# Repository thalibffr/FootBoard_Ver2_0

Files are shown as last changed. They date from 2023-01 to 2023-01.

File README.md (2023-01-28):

# Footboard ICHIRO Ver2.0

New Board Design for Foot Pressure of humanoid robot ICHIRO ITS

In this new design analog sensor data readings use ads1262

[Top view]
loadcell_v2 top

[Bottom view]
loadcell_v2 bottom

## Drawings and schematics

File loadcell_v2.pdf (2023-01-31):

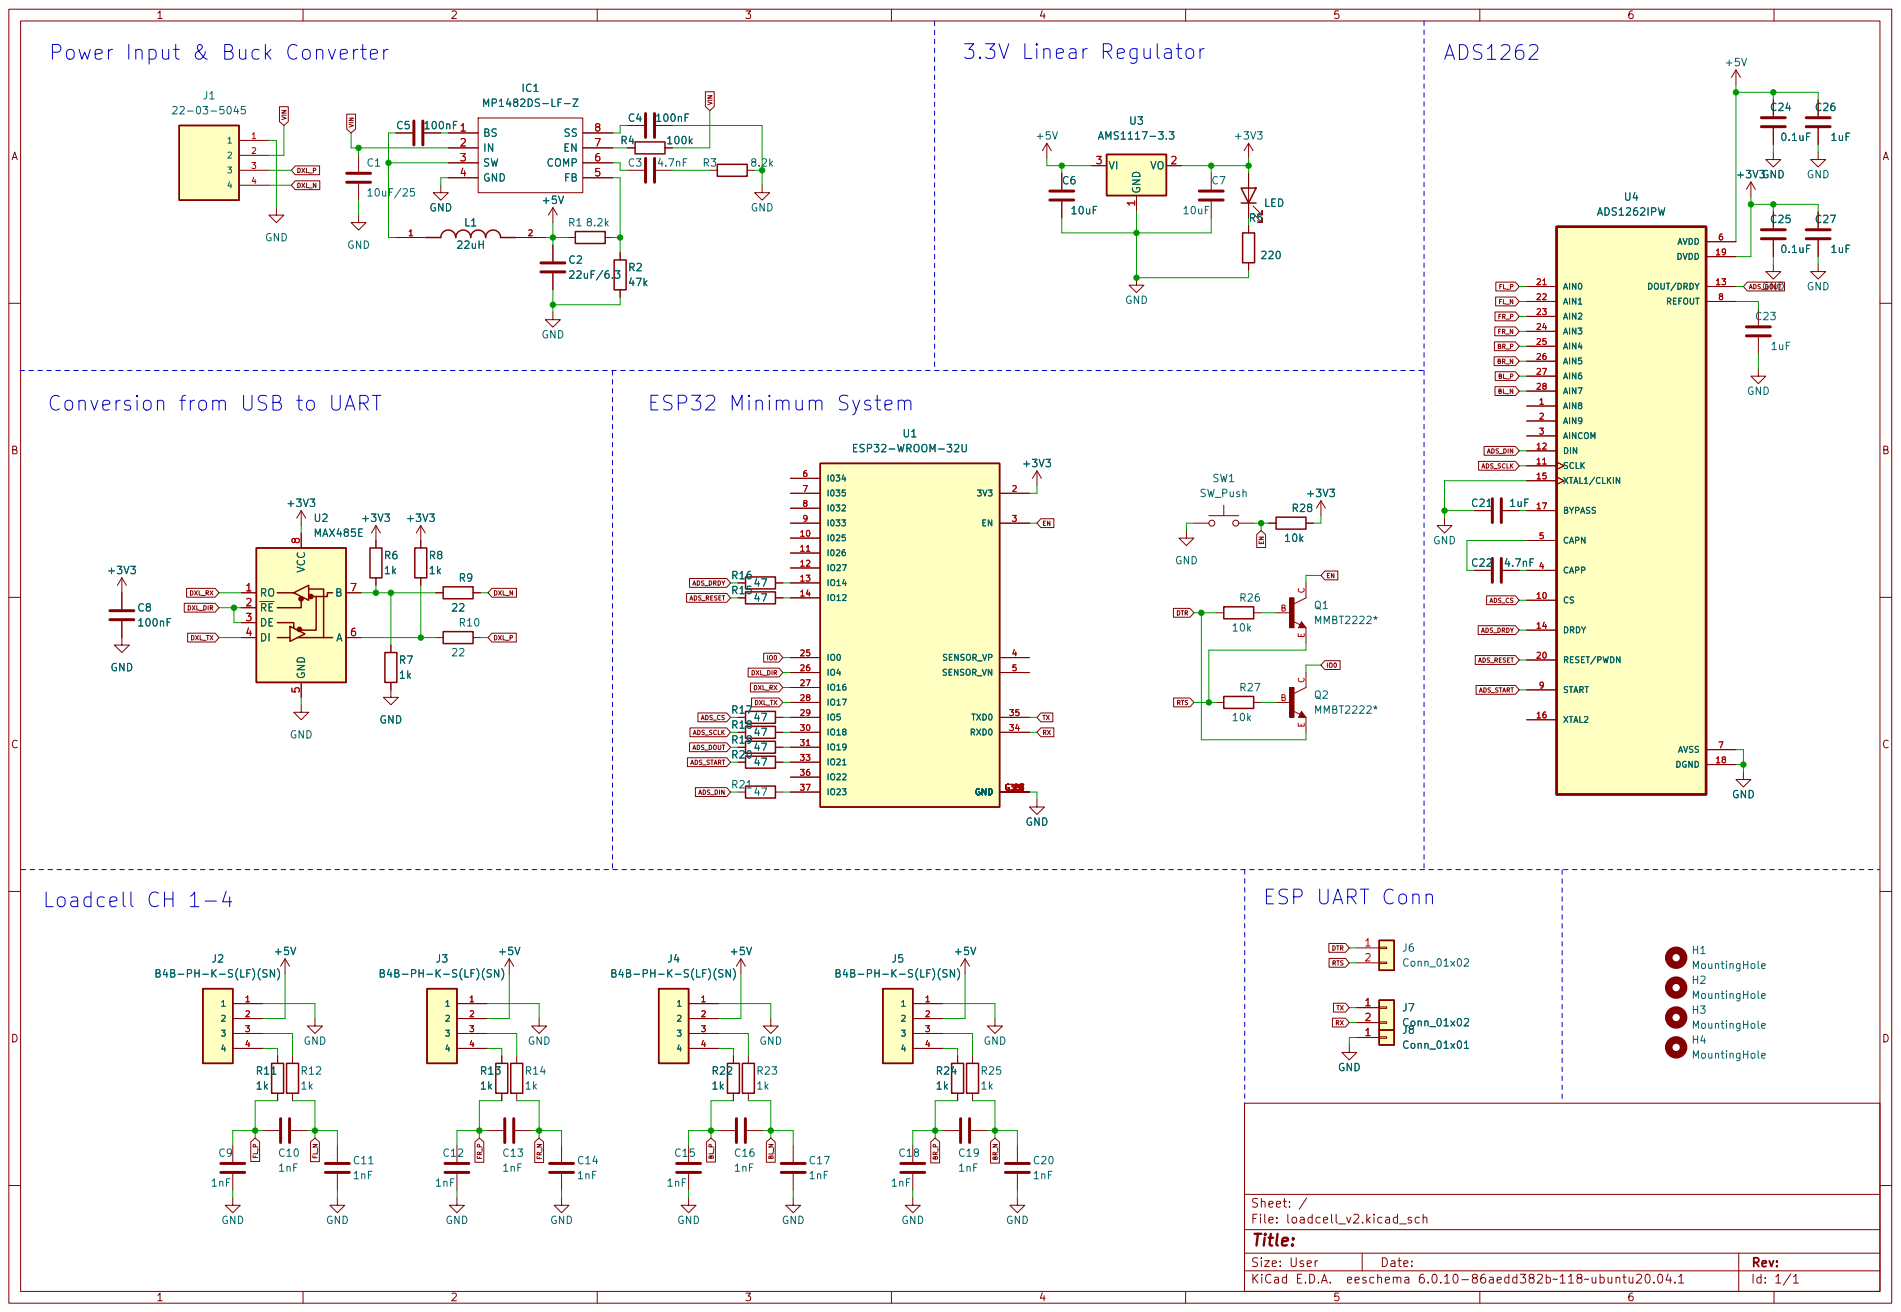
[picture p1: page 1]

Power Input & Buck Converter

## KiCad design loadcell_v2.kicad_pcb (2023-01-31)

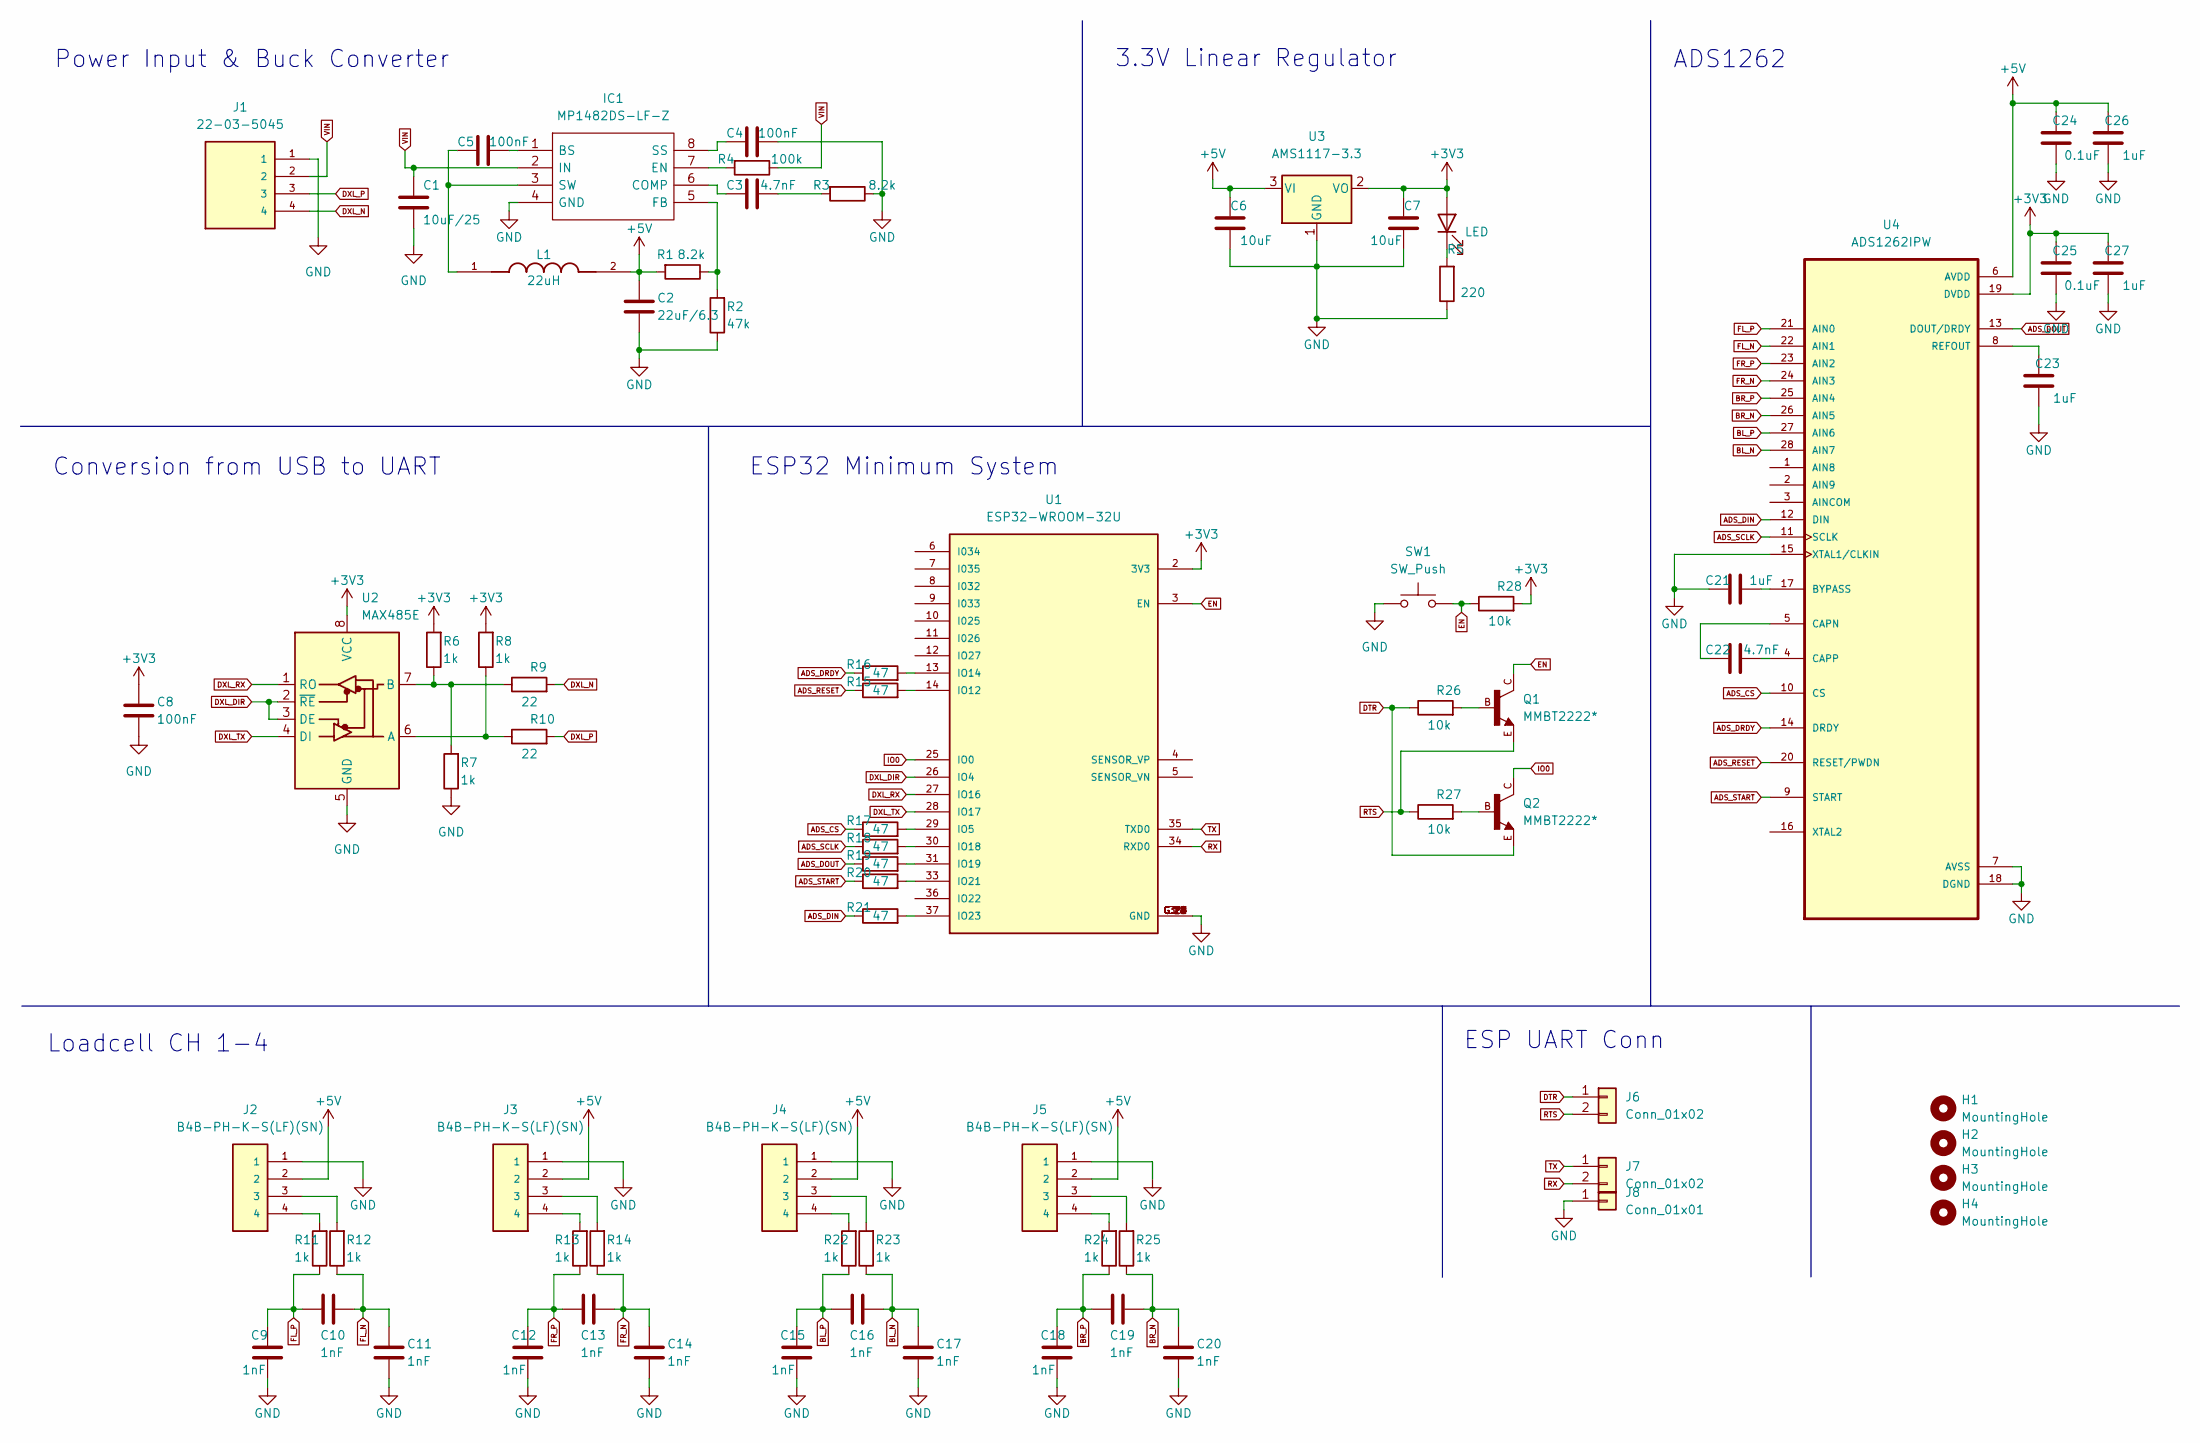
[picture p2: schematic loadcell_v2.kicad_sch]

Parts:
C1: 10uF/25; C_0805_2012Metric
C2: 22uF/6.3; C_0805_2012Metric
C3, C22: 4.7nF; C_0805_2012Metric
C4, C5, C8: 100nF; C_0805_2012Metric
C6, C7: 10uF; C_0805_2012Metric
C9, C10, C11, C12, C13, C14, C15, C16, C17, C18, C19, C20: 1nF; C_0805_2012Metric
C21, C23, C26, C27: 1uF; C_0805_2012Metric
C24, C25: 0.1uF; C_0805_2012Metric
D1: LED; LED_0805_2012Metric
H1, H2, H3, H4: MountingHole; MountingHole_3mm
IC1: MP1482DS-LF-Z; SOIC127P600X175-8N; Manufacturer_Part_Number MP1482DS-LF-Z; Mouser Part Number 946-MP1482DSLFZ
J1: 22-03-5045; MOLEX_22-03-5045; PARTREV B
J2, J3, J4, J5: B4B-PH-K-S(LF)(SN); JST_B4B-PH-K-S(LF)(SN)
J6, J7: Conn_01x02; PinHeader_1x02_P2.54mm_Vertical
J8: Conn_01x01; PinHeader_1x01_P2.54mm_Vertical
L1: 22uH; IND_VLS6045EX-3R3N; PARTREV N/A
Q1, Q2: MMBT2222*; SOT23-BEC
R1, R3: 8.2k; R_0805_2012Metric
R2: 47k; R_0805_2012Metric
R4: 100k; R_0805_2012Metric
R5: 220; R_0805_2012Metric
R6, R7, R8, R11, R12, R13, R14, R22, R23, R24, R25: 1k; R_0805_2012Metric
R9, R10: 22; R_0805_2012Metric
R15, R16, R17, R18, R19, R20, R21: 47; R_0805_2012Metric
R26, R27, R28: 10k; R_0805_2012Metric
SW1: SW_Push; SW_SPST_CK_RS282G05A3
U1: ESP32-WROOM-32U; XCVR_ESP32-WROOM-32U; PARTREV V1.9
U2: MAX485E; SOIC127P600X175-8N
U3: AMS1117-3.3; SOT229P700X180-4N
U4: ADS1262IPW; SOP65P640X120-28N

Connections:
+3V3: C7.2, C8.2, C25.2, C27.2, D1.2 (A), R6.2, R8.2, R28.2, U1.2 (3V3), U2.8 (VCC), U3.2 (VO), U4.19 (DVDD)
+5V: C2.2, C6.2, C24.2, C26.2, J2.2, J3.2, J4.2, J5.2, L1.2, R1.2, U3.3 (VI), U4.6 (AVDD)
ADS_CS: R17.1, U4.10 (CS)
ADS_DIN: R21.1, U4.12 (DIN)
ADS_DOUT: R19.1, U4.13 (DOUT/DRDY)
ADS_DRDY: R16.1, U4.14 (DRDY)
ADS_RESET: R15.1, U4.20 (RESET/PWDN)
ADS_SCLK: R18.1, U4.11 (SCLK)
ADS_START: R20.1, U4.9 (START)
BL_N: C16.2, C17.2, R23.1, U4.28 (AIN7)
BL_P: C15.2, C16.1, R22.1, U4.27 (AIN6)
BR_N: C19.2, C20.2, R25.1, U4.26 (AIN5)
BR_P: C18.2, C19.1, R24.1, U4.25 (AIN4)
DTR: J6.1, Q2.E, R26.1; also elsewhere on the board
DXL_DIR: U1.26 (IO4), U2.2 (~RE), U2.3 (DE)
DXL_N: J1.4, R9.2
DXL_P: J1.3, R10.2
DXL_RX: U1.27 (IO16), U2.1 (RO)
DXL_TX: U1.28 (IO17), U2.4 (DI)
EN: Q1.C, R28.1, SW1.2, U1.3 (EN)
FL_N: C10.2, C11.2, R12.1, U4.22 (AIN1)
FL_P: C9.2, C10.1, R11.1, U4.21 (AIN0)
FR_N: C13.2, C14.2, R14.1, U4.24 (AIN3)
FR_P: C12.2, C13.1, R13.1, U4.23 (AIN2)
GND: C1.2, C2.1, C4.1, C6.1, C7.1, C8.1, C9.1, C11.1, C12.1, C14.1, C15.1, C17.1, C18.1, C20.1, C21.1, C23.1, C24.1, C25.1, C26.1, C27.1, IC1.4 (GND), J1.1, J2.1, J3.1, J4.1, J5.1, J8.1, R2.1, R3.1, R5.1, R7.1, SW1.1, U1.1 (GND), U1.38 (GND), U1.G.11 (GND), U1.G.12 (GND), U1.G.13 (GND), U1.G.14 (GND), U1.G.15 (GND), U1.G.16 (GND), U1.G.17 (GND), U1.G.18 (GND), U1.G.19 (GND), U1.G.20 (GND), U1.G.21 (GND), U1.G.22 (GND), U2.5 (GND), U3.1 (GND), U4.7 (AVSS), U4.15 (XTAL1/CLKIN), U4.18 (DGND)
IO0: Q2.C, U1.25 (IO0)
unnamed: C3.1, R3.2
unnamed: C3.2, IC1.6 (COMP)
unnamed: C4.2, IC1.8 (SS)
unnamed: C5.1, IC1.1 (BS)
unnamed: C5.2, IC1.3 (SW), L1.1
unnamed: C21.2, U4.17 (BYPASS)
unnamed: C22.1, U4.4 (CAPP)
unnamed: C22.2, U4.5 (CAPN)
unnamed: C23.2, U4.8 (REFOUT)
unnamed: D1.1 (K), R5.2
unnamed: IC1.5 (FB), R1.1, R2.2
unnamed: IC1.7 (EN), R4.2
unnamed: J2.3, R12.2
unnamed: J2.4, R11.2
unnamed: J3.3, R14.2
unnamed: J3.4, R13.2
unnamed: J4.3, R23.2
unnamed: J4.4, R22.2
unnamed: J5.3, R25.2
unnamed: J5.4, R24.2
unnamed: Q1.B, R26.2
unnamed: Q2.B, R27.2
unnamed: R6.1, R7.2, R9.1, U2.7 (B)
unnamed: R8.1, R10.1, U2.6 (A)
unnamed: R15.2, U1.14 (IO12)
unnamed: R16.2, U1.13 (IO14)
unnamed: R17.2, U1.29 (IO5)
unnamed: R18.2, U1.30 (IO18)
unnamed: R19.2, U1.31 (IO19)
unnamed: R20.2, U1.33 (IO21)
unnamed: R21.2, U1.37 (IO23)
RTS: J6.2, Q1.E, R27.1; also elsewhere on the board
RX: J7.2, U1.34 (RXD0); also elsewhere on the board
TX: J7.1, U1.35 (TXD0); also elsewhere on the board
VIN: C1.1, IC1.2 (IN), J1.2, R4.1

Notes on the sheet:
3.3V Linear Regulator
Loadcell CH 1-4
Power Input & Buck Converter
ESP32 Minimum System
Conversion from USB to UART
ADS1262
ESP UART Conn

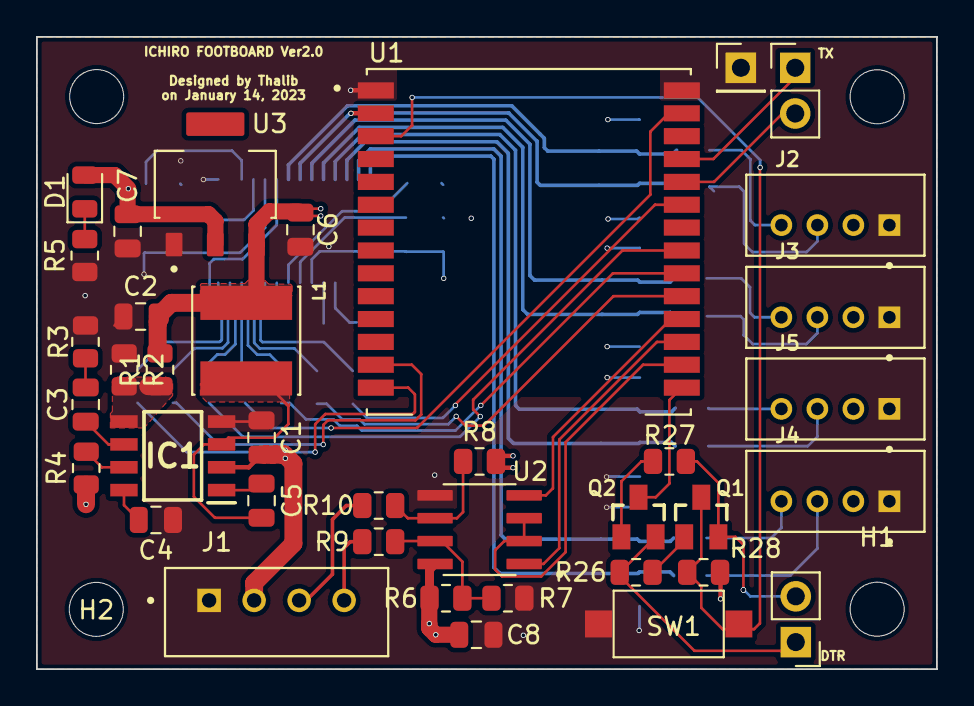
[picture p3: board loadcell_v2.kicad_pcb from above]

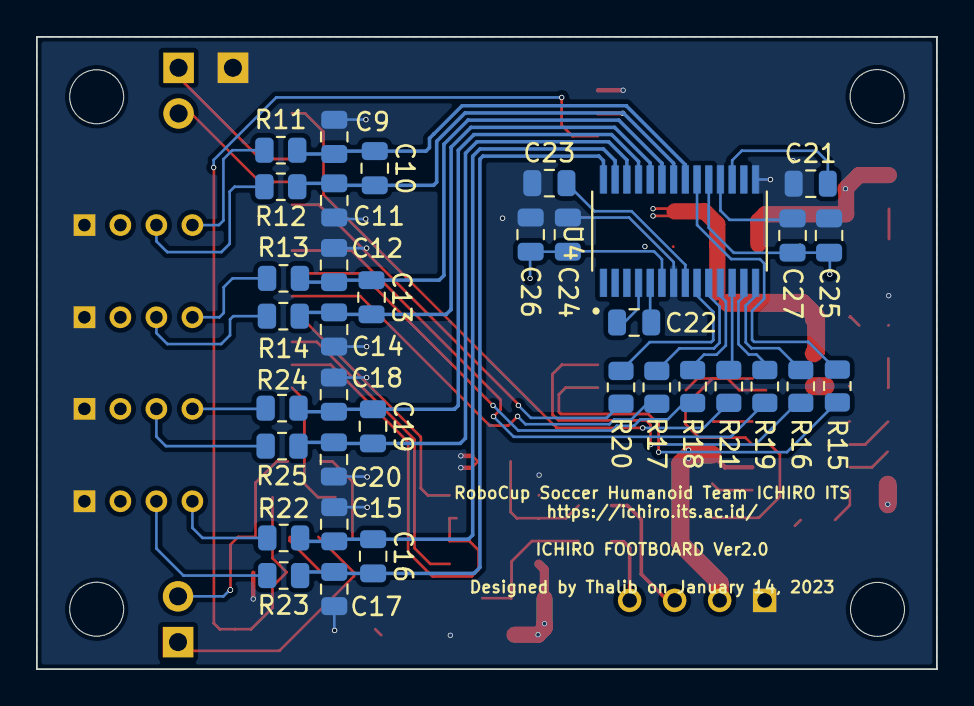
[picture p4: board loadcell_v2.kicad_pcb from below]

Board: 4 copper layers, 50.0 x 35.1 mm, 77 parts (35 on the bottom side), 61 nets.

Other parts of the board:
DTR: Conn_01x02; PinHeader_1x02_P2.54mm_Vertical
TX: Conn_01x02; PinHeader_1x02_P2.54mm_Vertical

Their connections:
DTR: DTR.1; also elsewhere on the board
RTS: DTR.2; also elsewhere on the board
RX: TX.2; also elsewhere on the board
TX: TX.1; also elsewhere on the board

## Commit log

2023-01-28 add 3d board imagee
2023-01-31 add schematic pdf
2023-01-31 add sch & brd file
    [loadcell_v2.kicad_pcb, loadcell_v2.kicad_sch]
